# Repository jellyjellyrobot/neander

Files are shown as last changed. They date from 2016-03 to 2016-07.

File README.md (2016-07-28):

# Neander

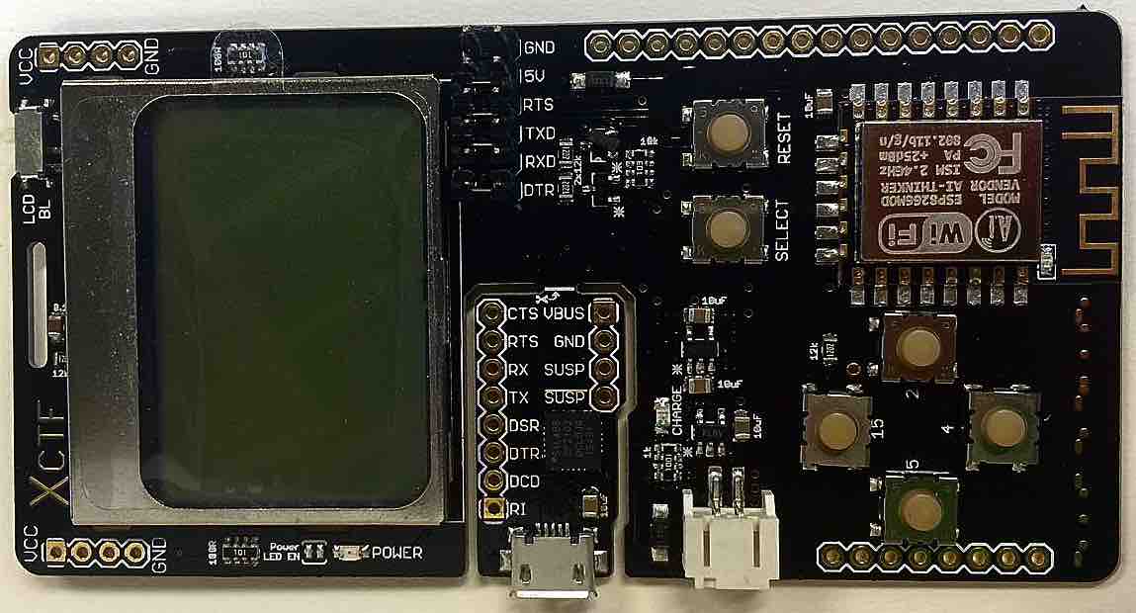
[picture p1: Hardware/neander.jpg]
Neander


The Neander is a microcontroller platform that is created for NUS Greyhats' X-CTF.

This board is based on the ESP8266 microcontroller series by Espressif and derives certain components from Adafruit's Feather and Sparkfun's Thing based on the same microcontroller platform.

## Specifications

- ESP8266 32 bit Microcontroller platform with Integrated 802.11 b/g/n
- Auto-Reset
- Deep Sleep option (enabled)
- 500mA 3.3V Voltage Regulator
- USB-Serial Interface (CP2102)
- 6 Buttons (including Reset)
- Lithium Polymer Charger
- Indicator LEDs (Charge, Power)
- Backlight LEDs and Switches

## Neander Accessory kit

The Neander comes with an accessory kit which includes the following

- Lithium Polymer Battery
- MicroUSB cable
- Short Lanyard (For CP2102)
- 10cm Dupont Jumper Cables (10 each: M-M, F-F, F-M)
- Single Row Headers 1*40 pin
- Double Row Headers 2*6 pin
- 6 Jumpers
- 2 Stickers

## Using the USB-Serial Adaptor

The on-board USB-Serial Adaptor is based on a Silabs CP2102 chip.

OS specific drivers can be found on the [manufacturer's website](http://www.silabs.com/products/mcu/Pages/USBtoUARTBridgeVCPDrivers.aspx). A tutorial on how to use this device can be found [here](https://learn.sparkfun.com/tutorials/cp2102-usb-to-serial-converter-hook-up-guide). The datasheet can be found [here](https://cdn.sparkfun.com/datasheets/BreakoutBoards/CP2102_v1.2.pdf).

## Interfacing with other electronics

The USB-Serial adaptor is supplied as a breakout board. If you need a serial adaptor "out in the field", you can choose to break it and solder on any 2.54mm compatible headers for convenience.

To interface the serial adaptor with other serial devices with the CP2102 in-situ, you may solder the double row headers found in the accessory packs and disconnect (desolder) all 5 SMD jumper pads.

## XCTF 2016

Here are the repositories for the [qualifiers] (https://github.com/NUSGreyhats/xctf-2016-quals-challenges) and [finals](https://github.com/NUSGreyhats/x-ctf-2016-finals).

## Contributors

Jacob  
Darell  
Yu Siang  
Jeremias

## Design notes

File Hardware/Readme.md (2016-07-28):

#Hardware

## Stages

This board was designed in 3 stages. 2 Prototypes were made (with mistakes :D) and the final board turned out pretty ok. Lucky us!

##Bill of Materials

The [Bill of Materials](https://docs.google.com/spreadsheets/d/1qAbk1U9EDFSMrGZ68tAHjeOSaGbgNGMX1J6-07fJV7c/edit?usp=sharing) can be found here!

## Production Writeups

Darell (@geekman) has produced a great writeup [here](http://irq5.io/2016/06/22/designing-the-x-ctf-2016-badge/)!

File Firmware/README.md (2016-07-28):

# Firmwares

## Firmware 1: XCTF

You can find the firmware provided during the competition [here](https://github.com/geekman/badger)! The writeup's [here](http://irq5.io/2016/07/19/x-ctf-2016-badge-firmware/)!

## Firmware 2: Test harness

This repository hosts the test harness for the ESP-8266 based Neander board.

## Arduino programming setup

The [Arduino IDE](https://www.arduino.cc/en/Main/Software) can be used to upload code to the Neander board.

To setup your Arduino IDE environment to compile and upload code to the Neander, you may refer to [this tutorial](https://learn.adafruit.com/adafruit-feather-huzzah-esp8266/using-arduino-ide).

## Serial programming/debugging setup

There are many serial programming utilities for the ESP8266 chips, we support [this](https://github.com/themadinventor/esptool). You can also use [this](https://github.com/igrr/esptool-ck). **YMMV**

``` sh
# installs esptool.py, a python utility that allows for serial programming and debugging of ESP8266 chips
pip install esptool
```

## Firmware Upload

The flash mode, size and frequency have to be set to the specific values based on the ESP12-F modules.

``` sh
esptool.py -p {insert port here} write_flash 0x00000 firmware/0x00000.bin 0x40000 firmware/0x40000.bin --flash_mode dio --flash_size 32m --flash_freq 40m
```

## Firmware Dump

This command dumps the flash memory from the region 0x0000 to 0x7490 to firmware/0x00000.bin.dump

``` sh
esptool.py -p {insert port here} read_flash 0x0000 0x7490 firmware/0x00000.bin.dump
```

## GCC Toolchain setup

We use [esp-open-sdk](https://github.com/pfalcon/esp-open-sdk), a collection of open-source utilities for compilation of source code to the xtensa instruction set architecture (used in ESP8266).

Once set up, you may reference the xtensa toolchain by 

```
export PATH={installation_dir}/esp-open-sdk/xtensa-lx106-elf/bin:$PATH
```

## Compilation and Upload of test suite

```sh
make rebuild
```

## Wiki

You can refer to [esp8266-wiki](https://github.com/esp8266/esp8266-wiki/wiki) learn more about the ESP8266, its features, architecture, boot process and memory map.

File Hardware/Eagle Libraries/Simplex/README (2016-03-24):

finest footprints for exotic devices. compatible with Eagle v6.0 or greater.

distributed under the GPLv3 license. provided as-is without any warranty. 

contains footprints for the following devices:

Simplex-Battery
    - Renata HU2032-LF Li 2032 battery holder

Simplex-Connectors
    - Lumberg KLBR4
    - Molex 0530470210
    - Molex 0530480210
    - Molex 0530470410
    - Molex 0530480410
    - Molex 0530470610
    - Molex 0530480610
    - Molex 78800001 mini SIM
    - Amphenol SIMLOCK "C707 10M006 000 2"
    - 2x4pin 3M IDC connector
    - 2x6pin 3M IDC connector
    - DG58C-B-02P-13 2 pole Degson Electronics screw terminal
    - DG58C-B-03P-13 3 pole Degson Electronics screw terminal
    - DG58C-B-04P-13 4 pole Degson Electronics screw terminal
    - DG58C-B-08P-13 8 pole Degson Electronics screw terminal

Simplex-DiscreteSemi
    - MOSFET-P channel - sot23-3, sot23-3 power, d-pak
    - MOSFET-N channel - sot23-3, sot23-3 power, d-pak
    - SMF05C

Simplex-FreqCtrl
    - 5x3.2mm crystal
    - 3.2x1.5mm crystal

Simplex-Fuses
    - 0805 resettable fuse
    - 1210 resettable fuse
    - Eastern Beaver Power Center 8

Simplex-ICs
    - DS3231
    - Vishay TSOP312x (vertical and horizontal)
    - Linear LTC2991
    - Texas Instruments TPS3613
    - Texas Instruments BQ24072
    - Texas Instruments ADS1110
    - Texas Instruments PGA2311
    - GlobalTop FGPMMOPA6H
    - sim900
    - STK461, STK463, STK465
    - linear regulators in a D2PAK package
    - Cypress FM24Vxx serial F-RAM
    - LM2674

Simplex-Jumpers
    - 4 way solder jumper

Simplex-rlc
    - 0805 inductor
    - yageo YC164 series resistor array
    - TO220 vertical and horizontal resistor

Simplex-Switches
    - 6x3.5mm tactile SPST-NO switch

author: Petre Rodan <petre.rodan@simplex.ro>
url:    https://github.com/rodan/Simplex-Eagle-Libraries

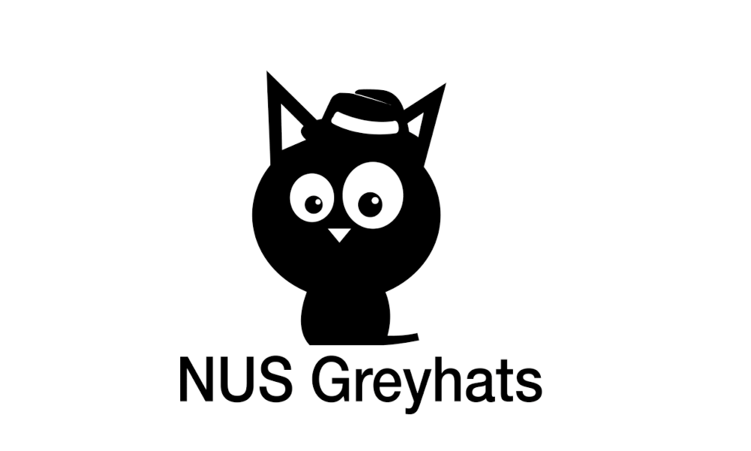
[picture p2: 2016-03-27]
Hardware/Eagle Libraries/GreyHats.bmp

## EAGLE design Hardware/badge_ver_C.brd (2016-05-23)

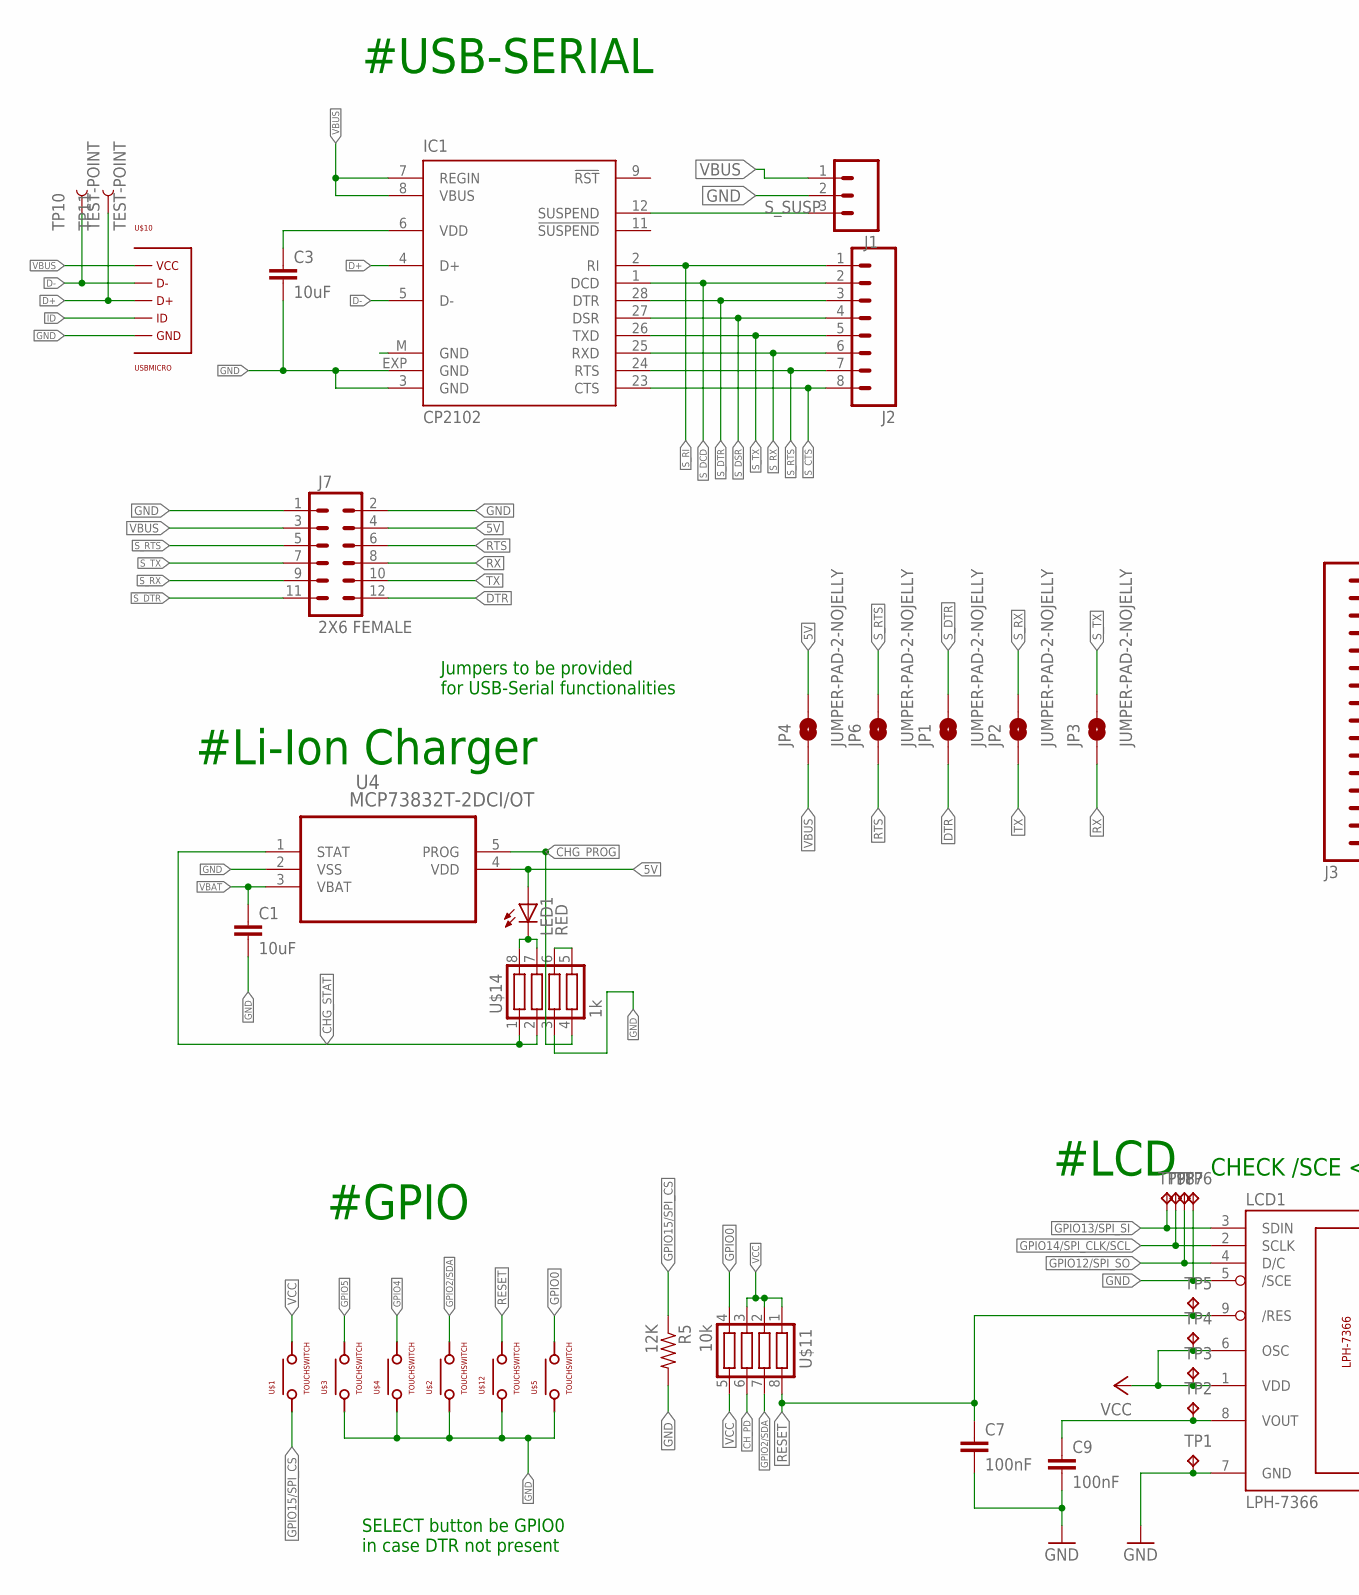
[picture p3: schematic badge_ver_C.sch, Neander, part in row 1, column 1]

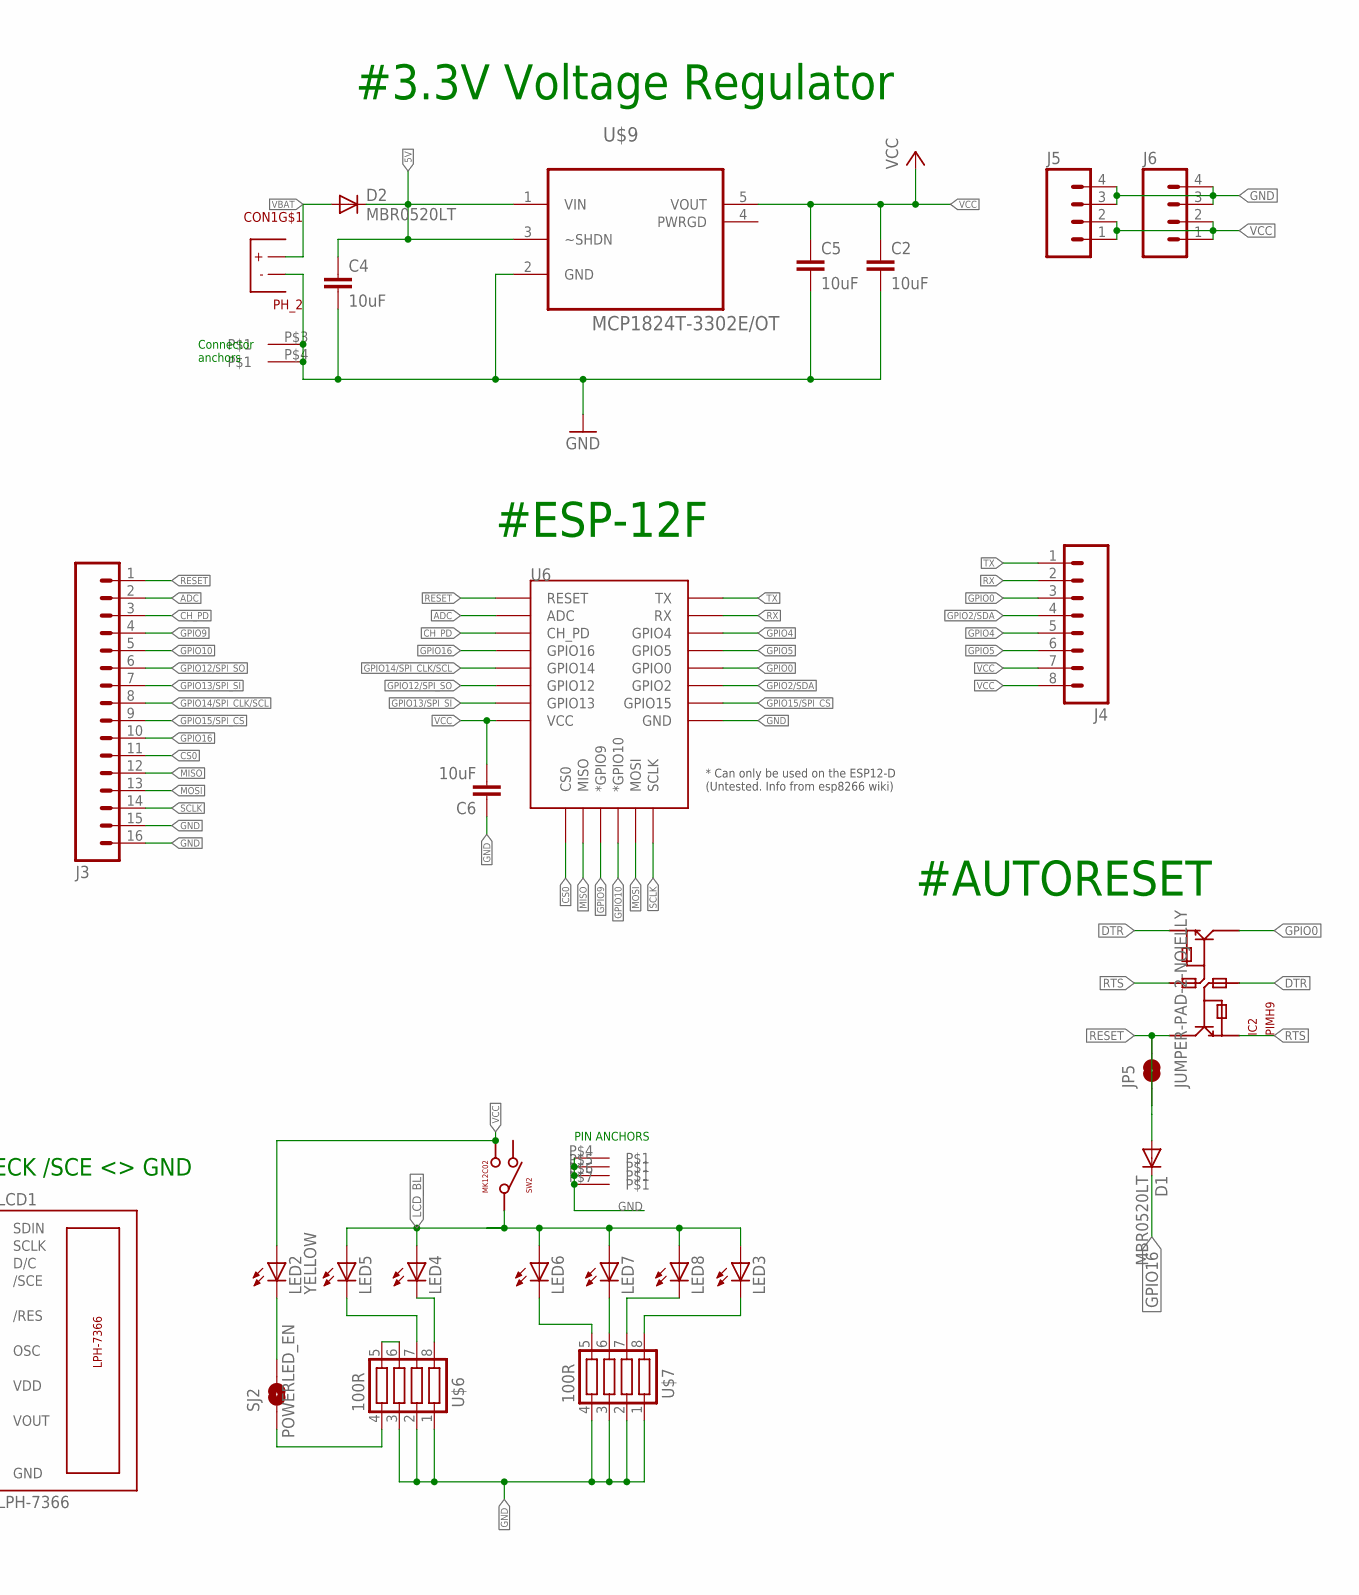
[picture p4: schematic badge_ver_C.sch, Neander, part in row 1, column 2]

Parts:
C1, C2, C3, C4, C5, C6: 10uF; 0805-CAP
C7, C9: 100nF; 0805-CAP
CON1: PH_2
D1, D2: MBR0520LT; SOD123
IC1: CP2102; MLP28
IC2: PIMH9; SOT457
J1: M03PTH; 1X03
J2: M08SILK_FEMALE_PTH; 1X08
J3: M16PTH; 1X16
J4: M08; 1X08_ROUND
J5, J6: M04PTH; 1X04
J7: 2X6 FEMALE; 2X6
JP1, JP2, JP3, JP4, JP5, JP6: JUMPER-PAD-2-NOJELLY; JELLYPAD-JUMPER-2-NO_NO_SILK
LCD1: LPH-7366
LED1: RED; SML0805
LED2: YELLOW; SML0805
LED3, LED4, LED5, LED6, LED7, LED8: LEDSML0805; SML0805
R5: 12K; 0805
SJ2: POWERLED_EN; SJ_2S-TRACE
SW2: MK12C02
TP1, TP2, TP3, TP4, TP5, TP6, TP7, TP8, TP9: TPB1,27; B1,27
TP10, TP11: TEST-POINT; PAD.02X.02_JELLY
U4: MCP73832T-2DCI/OT; SOT95P300X145-5N
U6: ESP12ESMD; ESP12E-SMD
U$1, U$2, U$3, U$4, U$5, U$12: TOUCHSWITCH; EVQQWN03W
U$6, U$7: 100R; YC164
U$9: MCP1824T-3302E/OT; SOT95P270X145-5N
U$10: USBMICRO
U$11: 10k; YC164
U$14: 1k; YC164

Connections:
5V: C4.1, D2.C, J7.4, JP4.2, LED1.A, U4.4 (VDD), U$9.1 (VIN), U$9.3 (~SHDN)
ADC: J3.2, U6.ADC
CHG_PROG: U4.5 (PROG), U$14.4
CHG_STAT: U4.1 (STAT), U$14.1, U$14.2
CH_PD: J3.3, U6.CH_PD, U$11.6
CS0: J3.11, U6.CS0
D+: IC1.4 (D+), TP11.P$1, U$10.P$D+
D-: IC1.5 (D-), TP10.P$1, U$10.P$D-
DTR: IC2.P$2, IC2.P$4, J7.12, JP1.1
GND: C1.2, C2.2, C3.2, C4.2, C5.2, C6.1, C7.2, C9.2, CON1.P$1, CON1.P$3, CON1.P$4, IC1.3 (GND), IC1.EXP (GND), J1.2, J3.15, J3.16, J5.3, J5.4, J6.3, J6.4, J7.1, J7.2, LCD1.5 (/SCE), LCD1.7 (GND), R5.2, SW2.P$4, SW2.P$5, SW2.P$6, SW2.P$7, TP1.TP, TP6.TP, U4.2 (VSS), U6.GND, U$2.P$1, U$2.P$4, U$3.P$1, U$3.P$4, U$4.P$1, U$4.P$4, U$5.P$1, U$5.P$4, U$6.1, U$6.2, U$6.3, U$7.1, U$7.2, U$7.3, U$7.4, U$9.2 (GND), U$10.P$GND, U$12.P$1, U$12.P$4, U$14.3
GPIO0: IC2.P$3, J4.3, U6.GPIO0, U$5.P$2, U$5.P$3, U$11.4
GPIO2/SDA: J4.4, U6.GPIO2, U$2.P$2, U$2.P$3, U$11.7
GPIO4: J4.5, U6.GPIO4, U$4.P$2, U$4.P$3
GPIO5: J4.6, U6.GPIO5, U$3.P$2, U$3.P$3
GPIO9: J3.4, U6.GPIO9 (*GPIO9)
GPIO10: J3.5, U6.GPIO10 (*GPIO10)
GPIO12/SPI_SO: J3.6, LCD1.4 (D/C), TP7.TP, U6.GPIO12
GPIO13/SPI_SI: J3.7, LCD1.3 (SDIN), TP9.TP, U6.GPIO13
GPIO14/SPI_CLK/SCL: J3.8, LCD1.2 (SCLK), TP8.TP, U6.GPIO14
GPIO15/SPI_CS: J3.9, R5.1, U6.GPIO15, U$1.P$1, U$1.P$4
GPIO16: D1.C, J3.10, U6.GPIO16
ID: U$10.P$ID
LCD_BL: LED3.A, LED4.A, LED5.A, LED6.A, LED7.A, LED8.A, SW2.P$2
MISO: J3.12, U6.MISO
MOSI: J3.13, U6.MOSI
unnamed: LED1.C, U$14.7, U$14.8
unnamed: U$14.5, U$14.6
unnamed: LED7.C, U$7.6
unnamed: LED8.C, U$7.7
unnamed: C9.1, LCD1.8 (VOUT), TP2.TP
unnamed: U$6.5, U$6.6
unnamed: LED4.C, U$6.8
unnamed: LED5.C, U$6.7
unnamed: LED3.C, U$7.8
unnamed: SJ2.1, U$6.4
unnamed: LED2.C, SJ2.2
unnamed: C3.1, IC1.6 (VDD)
unnamed: LED6.C, U$7.5
RESET: C7.1, D1.A, IC2.P$6, J3.1, JP5.1, JP5.2, LCD1.9 (/RES), TP5.TP, U6.RESET, U$11.8, U$12.P$2, U$12.P$3
RTS: IC2.P$1, IC2.P$5, J7.6, JP6.1
RX: J4.2, J7.8, JP3.1, U6.RXD0 (RX)
SCLK: J3.14, U6.SCLK
S_CTS: IC1.23 (CTS), J2.8
S_DCD: IC1.1 (DCD), J2.2
S_DSR: IC1.27 (DSR), J2.4
S_DTR: IC1.28 (DTR), J2.3, J7.11, JP1.2
S_RI: IC1.2 (RI), J2.1
S_RTS: IC1.24 (RTS), J2.7, J7.5, JP6.2
S_RX: IC1.25 (RXD), J2.6, J7.9, JP2.2
S_SUSP: IC1.12 (SUSPEND), J1.3
S_TX: IC1.26 (TXD), J2.5, J7.7, JP3.2
TX: J4.1, J7.10, JP2.1, U6.TXD0 (TX)
VBAT: C1.1, CON1.P$2, D2.A, U4.3 (VBAT)
VBUS: IC1.7 (REGIN), IC1.8 (VBUS), J1.1, J7.3, JP4.1, U$10.P$VCC
VCC: C2.1, C5.1, C6.2, J4.7, J4.8, J5.1, J5.2, J6.1, J6.2, LCD1.1 (VDD), LCD1.6 (OSC), LED2.A, SW2.P$3, TP3.TP, TP4.TP, U6.VCC, U$1.P$2, U$1.P$3, U$9.5 (VOUT), U$11.1, U$11.2, U$11.3, U$11.5

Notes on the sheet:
SELECT button be GPIO0 in case DTR not present
#LCD
#Li-Ion Charger
#3.3V Voltage Regulator
#USB-SERIAL
#GPIO
#AUTORESET
#ESP-12F
Jumpers to be provided for USB-Serial functionalities
CHECK /SCE <> GND
Connector anchors
PIN ANCHORS

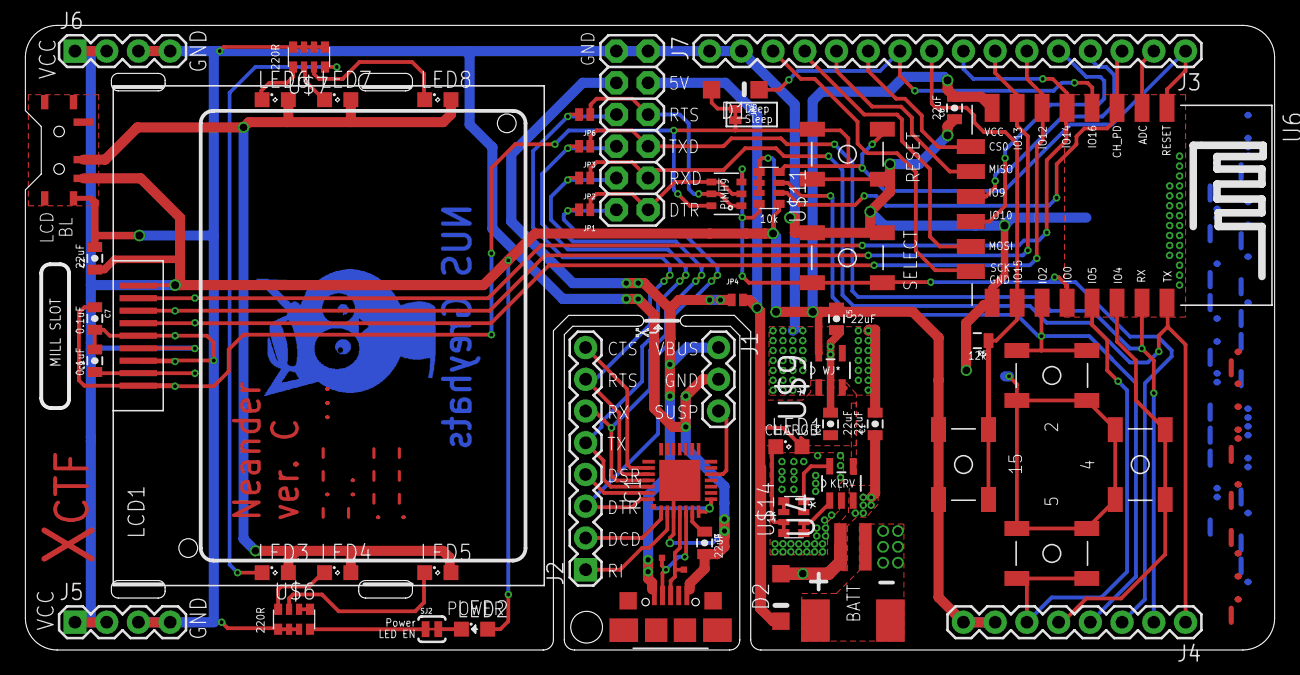
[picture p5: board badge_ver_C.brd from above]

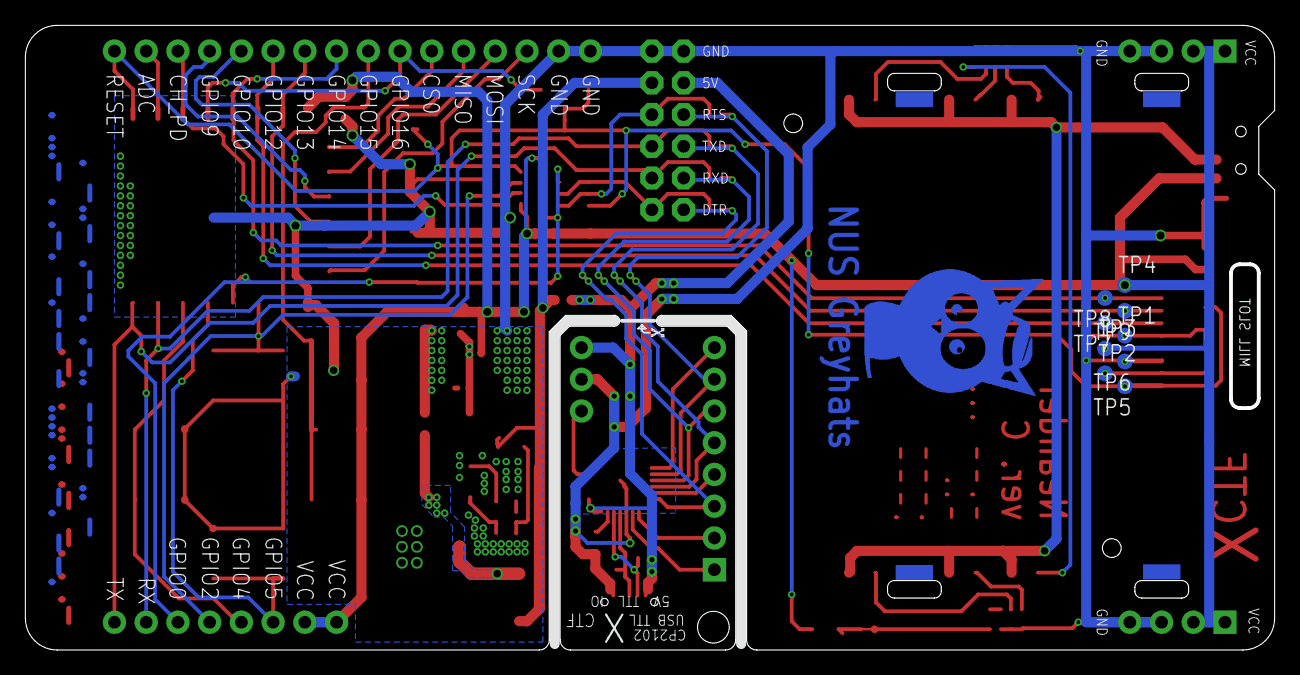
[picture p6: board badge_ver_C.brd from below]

Board: 2 copper layers, 100.0 x 50.0 mm, 63 parts (9 on the bottom side), 54 nets.

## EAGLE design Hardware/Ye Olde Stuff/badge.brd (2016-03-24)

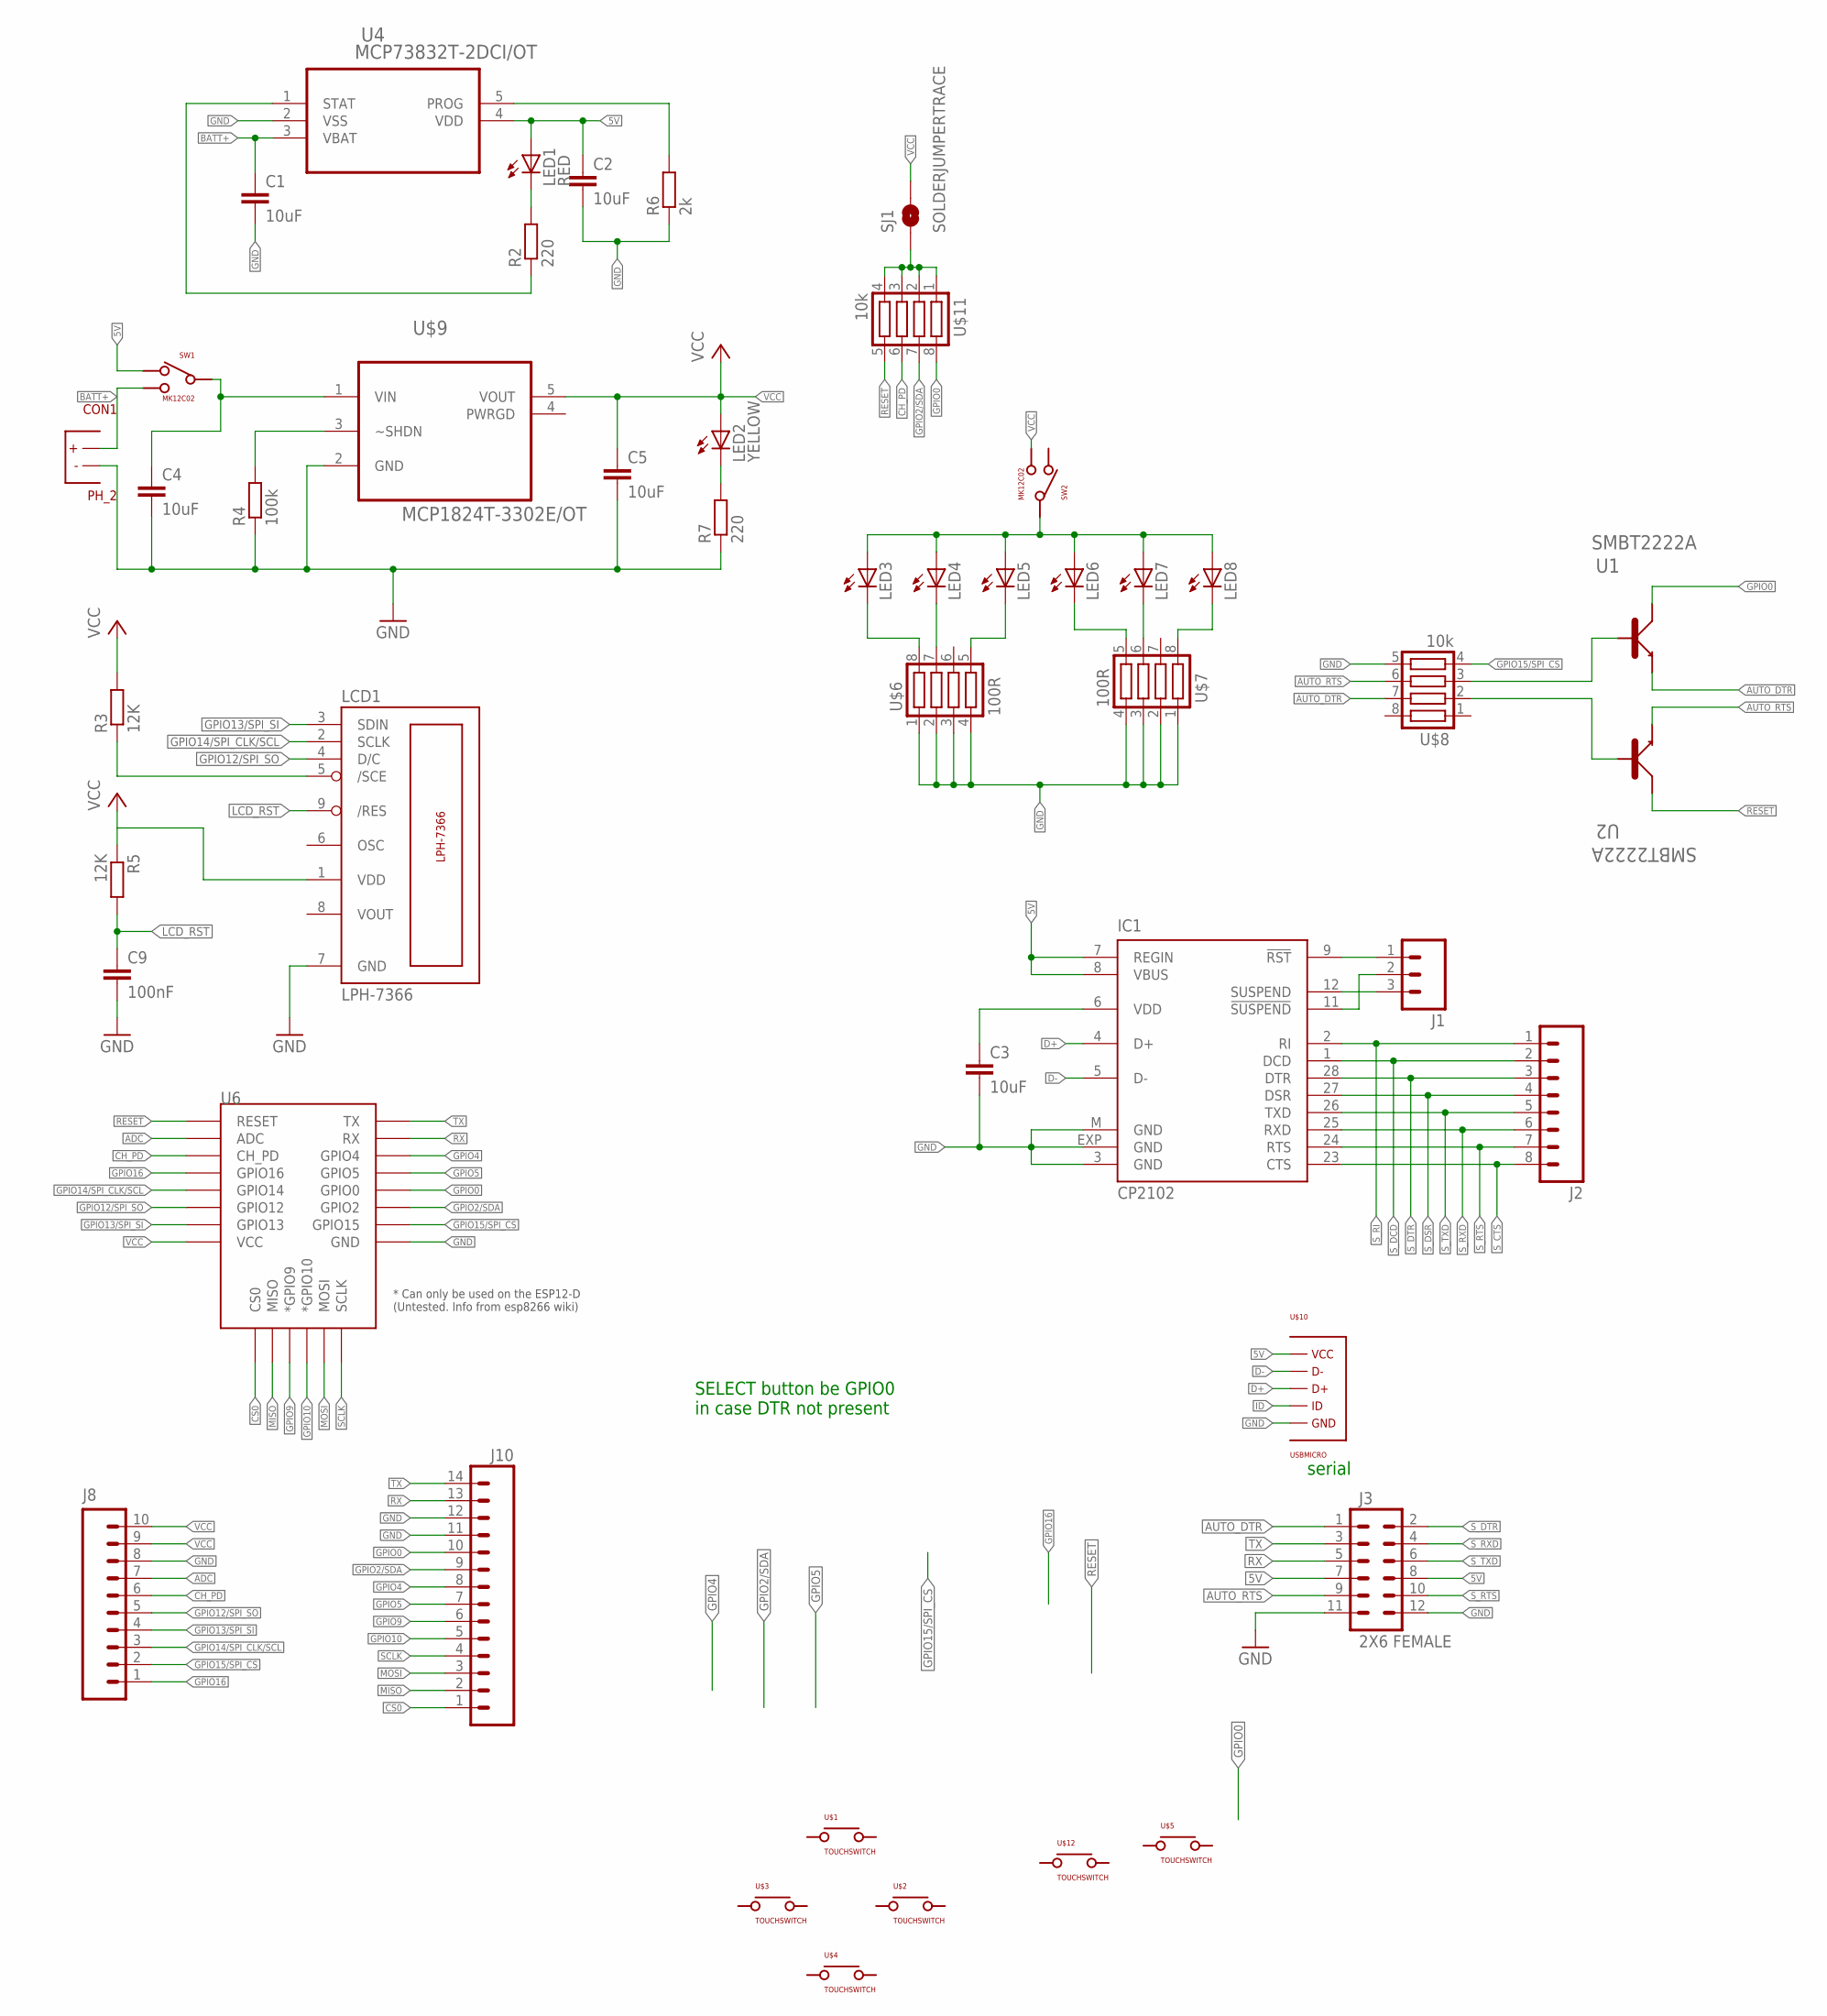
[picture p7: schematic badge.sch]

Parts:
C1, C2, C3, C4, C5: 10uF; C0603K
C9: 100nF; C0603K
CON1: PH_2
IC1: CP2102; MLP28
J1: M03PTH; 1X03
J2: M08SILK_FEMALE_PTH; 1X08
J3: 2X6 FEMALE; 2X6
J8: M10SILK_FEMALE_PTH; 1X10
J10: M14; 1X14
LCD1: LPH-7366
LED1: RED; SML0805
LED2: YELLOW; SML0805
LED3, LED4, LED5, LED6, LED7, LED8: LEDSML0805; SML0805
R2, R7: 220; R0603W
R3, R5: 12K; R0603W
R4: 100k; R0603W
R6: 2k; R0603W
SJ1: SOLDERJUMPERTRACE; SJ_2S-TRACE
SW1, SW2: MK12C02
U1, U2: SMBT2222A; SOT95P290X110-3N
U4: MCP73832T-2DCI/OT; SOT95P300X145-5N
U6: ESP12ESMD; ESP12E-SMD
U$1, U$2, U$3, U$4, U$5, U$12: TOUCHSWITCH; EVQQWN03W
U$6, U$7: 100R; YC164
U$8, U$11: 10k; YC164
U$9: MCP1824T-3302E/OT; SOT95P270X145-5N
U$10: USBMICRO

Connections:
5V: C2.1, IC1.7 (REGIN), IC1.8 (VBUS), J3.7, J3.8, LED1.A, SW1.P$2, U4.4 (VDD), U$10.P$VCC
ADC: J8.7, U6.ADC
AUTO_DTR: J3.1, U1.2 (E), U$8.7
AUTO_RTS: J3.9, U2.2 (E), U$8.6
BATT+: C1.1, CON1.P$2, SW1.P$3, U4.3 (VBAT)
CH_PD: J8.6, U6.CH_PD, U$11.6
CS0: J10.1, U6.CS0
D+: IC1.4 (D+), U$10.P$D+
D-: IC1.5 (D-), U$10.P$D-
GND: C1.2, C2.2, C3.2, C4.2, C5.2, C9.2, CON1.P$1, IC1.3 (GND), IC1.EXP (GND), IC1.M (GND), J3.11, J3.12, J8.8, J10.11, J10.12, LCD1.7 (GND), R4.1, R6.1, R7.1, U4.2 (VSS), U6.GND, U$6.1, U$6.2, U$6.3, U$6.4, U$7.1, U$7.2, U$7.3, U$7.4, U$8.5, U$9.2 (GND), U$10.P$GND
GPIO0: J10.10, U1.3 (C), U6.GPIO0, U$11.8
GPIO2/SDA: J10.9, U6.GPIO2, U$11.7
GPIO4: J10.8, U6.GPIO4
GPIO5: J10.7, U6.GPIO5
GPIO9: J10.6, U6.GPIO9 (*GPIO9)
GPIO10: J10.5, U6.GPIO10 (*GPIO10)
GPIO12/SPI_SO: J8.5, LCD1.4 (D/C), U6.GPIO12
GPIO13/SPI_SI: J8.4, LCD1.3 (SDIN), U6.GPIO13
GPIO14/SPI_CLK/SCL: J8.3, LCD1.2 (SCLK), U6.GPIO14
GPIO15/SPI_CS: J8.2, U6.GPIO15, U$8.4
GPIO16: J8.1, U6.GPIO16
ID: U$10.P$ID
LCD_RST: C9.1, LCD1.9 (/RES), R5.2
MISO: J10.2, U6.MISO
MOSI: J10.3, U6.MOSI
unnamed: C4.1, SW1.P$1, U$9.1 (VIN)
unnamed: LED3.A, LED4.A, LED5.A, LED6.A, LED7.A, LED8.A, SW2.P$1
unnamed: LCD1.5 (/SCE), R3.1
unnamed: R4.2, U$9.3 (~SHDN)
unnamed: SJ1.1, U$11.1, U$11.2, U$11.3, U$11.4
unnamed: R6.2, U4.5 (PROG)
unnamed: LED2.C, R7.2
unnamed: LED7.C, U$7.6
unnamed: LED1.C, R2.2
unnamed: R2.1, U4.1 (STAT)
unnamed: LED3.C, U$6.8
unnamed: LED4.C, U$6.7
unnamed: LED5.C, U$6.5
unnamed: U1.1 (B), U$8.3
unnamed: IC1.11 (!SUSPEND), J1.2
unnamed: IC1.12 (SUSPEND), J1.3
unnamed: U2.1 (B), U$8.2
unnamed: IC1.9 (!RST), J1.1
unnamed: C3.1, IC1.6 (VDD)
unnamed: LED6.C, U$7.5
unnamed: LED8.C, U$7.8
RESET: U2.3 (C), U6.RESET, U$11.5
RX: J3.5, J10.13, U6.RXD0 (RX)
SCLK: J10.4, U6.SCLK
S_CTS: IC1.23 (CTS), J2.8
S_DCD: IC1.1 (DCD), J2.2
S_DSR: IC1.27 (DSR), J2.4
S_DTR: IC1.28 (DTR), J2.3, J3.2
S_RI: IC1.2 (RI), J2.1
S_RTS: IC1.24 (RTS), J2.7, J3.10
S_RXD: IC1.25 (RXD), J2.6, J3.4
S_TXD: IC1.26 (TXD), J2.5, J3.6
TX: J3.3, J10.14, U6.TXD0 (TX)
VCC: C5.1, J8.9, J8.10, LCD1.1 (VDD), LED2.A, R3.2, R5.1, SJ1.2, SW2.P$3, U6.VCC, U$9.5 (VOUT)

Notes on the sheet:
serial
SELECT button be GPIO0 in case DTR not present

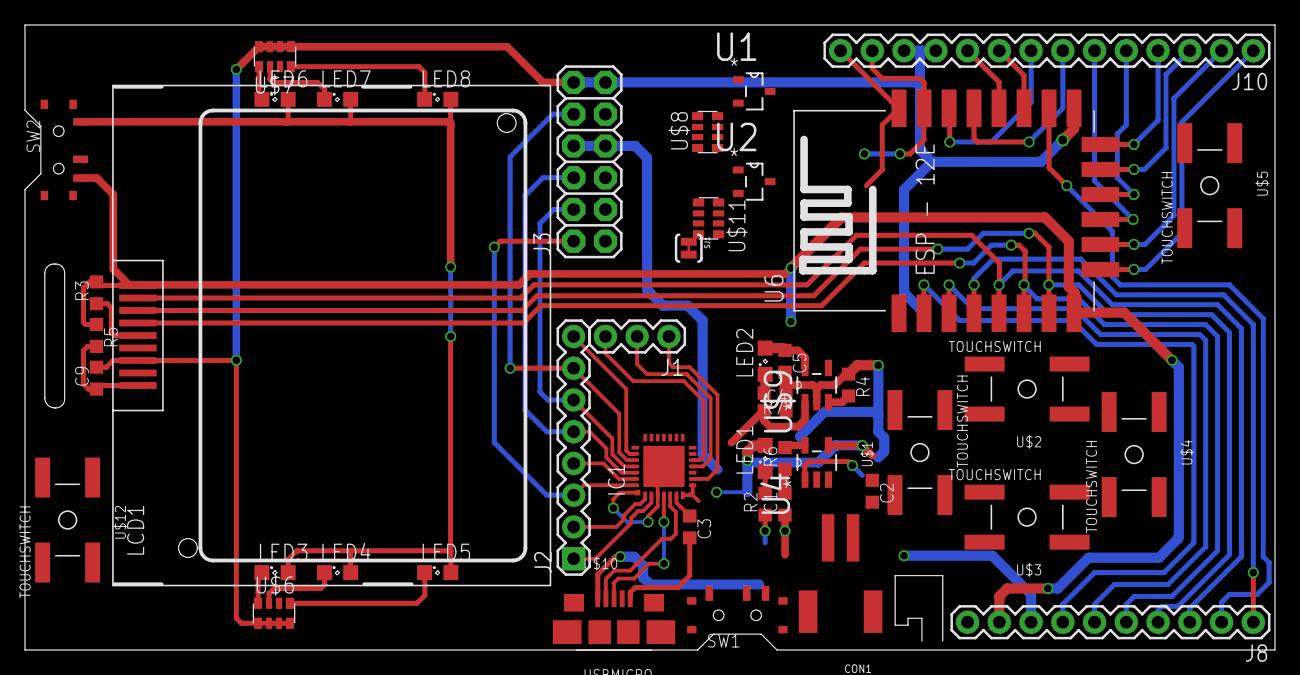
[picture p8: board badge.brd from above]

Board: 2 copper layers, 100.0 x 50.0 mm, 47 parts (0 on the bottom side), 58 nets.

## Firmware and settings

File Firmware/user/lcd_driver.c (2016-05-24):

#include "ets_sys.h"
#include "osapi.h"
#include "c_types.h"
#include "gpio.h"
#include "os_type.h"
#include "user_config.h"
#include "user_interface.h"
#include "stdout/stdout.h"
#include "pcd8544/pcd8544.h"
#include "easygpio/easygpio.h"

//http://www.introtoarduino.com/utils/pcd8544.html

static uint8_t test_logo[] = {
  0x15, 0x00, 0x01, 0x6C, 0x11, 0x6C, 0x00, 0x7C, 0x44, 0x44, 0x00, 0x04, 0x7C, 0x04, 0x00, 0x7C, 0x14, 0x14, 0x00, 0x00, 0x00, 0x00, 0x00, 0x7C, 0x08, 0x10, 0x7C, 0x00, 0x7C, 0x54, 0x54, 0x00, 0x78, 0x14, 0x78, 0x00, 0x7C, 0x08, 0x10, 0x7C, 0x00, 0x7C, 0x44, 0x38, 0x00, 0x7C, 0x54, 0x54, 0x00, 0x7C, 0x14, 0x68, 0x00, 0x00, 0x00, 0x00, 0x00, 0x3C, 0x40, 0x3C, 0x00, 0x00, 0x7C, 0x00, 0x40, 0x00, 0x78, 0x14, 0x78, 0x00, 0x00, 0x00, 0x00, 0x00, 0x00, 0x00, 0x00, 0x00, 0x00, 0x01, 0x00, 0x01, 0x00, 0x15,
  0x00, 0x00, 0x00, 0x01, 0x1F, 0x01, 0x00, 0x1F, 0x15, 0x15, 0x00, 0x17, 0x15, 0x1D, 0x00, 0x01, 0x1F, 0x01, 0x00, 0x00, 0x00, 0x00, 0x00, 0x17, 0x15, 0x1D, 0x00, 0x1F, 0x10, 0x1F, 0x00, 0x11, 0x1F, 0x11, 0x00, 0x01, 0x1F, 0x01, 0x00, 0x1F, 0x15, 0x15, 0x00, 0x00, 0x00, 0x00, 0x00, 0x00, 0x00, 0x00, 0x00, 0x00, 0x00, 0x00, 0x00, 0x00, 0x00, 0x00, 0x00, 0x00, 0x00, 0x00, 0x00, 0x00, 0x00, 0x00, 0x00, 0x00, 0x00, 0x00, 0x00, 0x00, 0x00, 0x00, 0x00, 0x00, 0x00, 0x00, 0x00, 0x00, 0x00, 0x00, 0x00, 0x00,
  0x00, 0x00, 0x00, 0x00, 0x00, 0x00, 0x00, 0x00, 0x00, 0x00, 0x00, 0x00, 0x00, 0x00, 0x00, 0x00, 0x00, 0x00, 0x00, 0x00, 0x00, 0x00, 0x00, 0x00, 0x00, 0x00, 0x00, 0x00, 0x00, 0x00, 0x00, 0x00, 0x00, 0x00, 0x00, 0x00, 0x00, 0x00, 0x00, 0x00, 0x00, 0x00, 0x00, 0x00, 0x00, 0x00, 0x00, 0x00, 0x00, 0x00, 0x00, 0x00, 0x00, 0x00, 0x00, 0x00, 0x00, 0x00, 0x00, 0x00, 0x00, 0x00, 0x00, 0x00, 0x00, 0x00, 0x00, 0x00, 0x00, 0x00, 0x00, 0x00, 0x00, 0x00, 0x00, 0x00, 0x00, 0x00, 0x00, 0x00, 0x00, 0x00, 0x00, 0x00,
  0x00, 0x00, 0x00, 0x00, 0x00, 0x00, 0x00, 0x00, 0x00, 0x00, 0x00, 0x00, 0x00, 0x00, 0x00, 0x00, 0x00, 0x00, 0x00, 0x00, 0x00, 0x00, 0x00, 0x00, 0x00, 0x00, 0x00, 0x00, 0x00, 0x00, 0x00, 0x00, 0x00, 0x00, 0x00, 0x00, 0x00, 0x00, 0x00, 0x00, 0x00, 0x00, 0x00, 0x00, 0x00, 0x00, 0x00, 0x00, 0x00, 0x00, 0x00, 0x00, 0x00, 0x00, 0x00, 0x00, 0x00, 0x00, 0x00, 0x00, 0x00, 0x00, 0x00, 0x00, 0x00, 0x00, 0x00, 0x00, 0x00, 0x00, 0x00, 0x00, 0x00, 0x00, 0x00, 0x00, 0x00, 0x00, 0x00, 0x00, 0x00, 0x00, 0x00, 0x00,
  0x00, 0x00, 0x00, 0x00, 0x00, 0x00, 0x00, 0x00, 0x00, 0x00, 0x00, 0x00, 0x00, 0x00, 0x00, 0x00, 0x00, 0x00, 0x00, 0x00, 0x00, 0x00, 0x00, 0x00, 0x00, 0x00, 0x00, 0x00, 0x00, 0x00, 0x00, 0x00, 0x00, 0x00, 0x00, 0x00, 0x00, 0x00, 0x00, 0x00, 0x00, 0x00, 0x00, 0x00, 0x00, 0x00, 0x00, 0x00, 0x00, 0x00, 0x00, 0x00, 0x00, 0x00, 0x00, 0x00, 0x00, 0x00, 0x00, 0x00, 0x00, 0x00, 0x00, 0x00, 0x00, 0x00, 0x00, 0x00, 0x00, 0x00, 0x00, 0x00, 0x00, 0x00, 0x00, 0x00, 0x00, 0x00, 0x00, 0x00, 0x00, 0x00, 0x00, 0x00,
  0xA8, 0x00, 0x80, 0x00, 0x80, 0x00, 0x00, 0x00, 0x00, 0x00, 0x00, 0x00, 0x00, 0x00, 0x00, 0x00, 0x00, 0x00, 0x00, 0x00, 0x00, 0x00, 0x00, 0x00, 0x00, 0x00, 0x00, 0x00, 0x00, 0x00, 0x00, 0x00, 0x00, 0x00, 0x00, 0x00, 0x00, 0x00, 0x00, 0x00, 0x00, 0x00, 0x00, 0x00, 0x00, 0x00, 0x00, 0x00, 0x00, 0x00, 0x00, 0x00, 0x00, 0x00, 0x00, 0x00, 0x00, 0x00, 0x00, 0x00, 0x00, 0x00, 0x00, 0x00, 0x00, 0x00, 0x00, 0x00, 0x00, 0x00, 0x00, 0x00, 0x00, 0x00, 0x00, 0x00, 0x00, 0x00, 0x00, 0x80, 0x00, 0x80, 0x00, 0xA8
};

#define user_procLcdUpdatePeriod 350
#define user_procTaskPrio 0
#define user_procTaskQueueLen 1

static volatile os_timer_t loop_timer;
os_event_t user_procTaskQueue[user_procTaskQueueLen];
static PCD8544_Settings pcd8544_settings;
static int contrast = 50;

void user_init(void);
static void loop(os_event_t *events);
static void nop_procTask(os_event_t *events);
static bool blah[10];


//Main code function
static void ICACHE_FLASH_ATTR
loop(os_event_t *events) {
  static uint32_t loopIterations = 0;
  loopIterations+=1;
  PCD8544_setContrast(contrast);
  if (loopIterations < 10) {
    PCD8544_lcdImage(test_logo);
  } else if (loopIterations == 10){
    PCD8544_lcdClear();
  } else {

    // Draw a Box
    PCD8544_drawLine();
    int a=0;
    PCD8544_gotoXY(10,1);
    // Put text in Box
    if (blah[0] && blah[1] && blah[2] && blah[3] && blah[4] && blah[5] && blah[6] && blah[7] && blah[8] && blah[9]){
      PCD8544_lcdPrint("TEST COMP");
    }else{
      PCD8544_lcdPrint("XCTF TEST");
    }
    
    PCD8544_gotoXY(24,2);

    if (gpio_input_get() & 1) {
      PCD8544_lcdCharacter('H');
      blah[5] = true;
    }else{
      PCD8544_lcdCharacter('h');
      blah[0] = true;
    }

    if (gpio_input_get() >> 2 & 1) {
      PCD8544_lcdCharacter('E');
      blah[5+1] = true;
    }else{
      PCD8544_lcdCharacter('e');
      blah[1] = true;
    }

    if (gpio_input_get() >> 4 & 1) {
      PCD8544_lcdCharacter('L');
      blah[5+2] = true;
    }else{
      PCD8544_lcdCharacter('l');
      blah[2] = true;
    }

    if (gpio_input_get() >> 5 & 1) {
      PCD8544_lcdCharacter('L');
      blah[5+3] = true;
    }else{
      PCD8544_lcdCharacter('l');
      if (contrast != 0){
        contrast--;
      }
      blah[3] = true;
    }

    if (!(gpio_input_get() >> 15 & 1)) {
      PCD8544_lcdCharacter('O');
      blah[5+4] = true;
    }else{
      PCD8544_lcdCharacter('o');
      if (contrast != 100){
        contrast++;
      }
      blah[4] = true;
    }

    if (loopIterations & 1){
      PCD8544_lcdCharacter(' ');
      PCD8544_lcdCharacter('=');
      // Draw + at this position
      PCD8544_gotoXY(10,2);
      PCD8544_lcdCharacter('=');
    } else {
      //PCD8544_gotoXY(24,2);
      PCD8544_lcdCharacter(' ');
      PCD8544_lcdCharacter('-');
      // Draw - at this position
      PCD8544_gotoXY(10,2);
      PCD8544_lcdCharacter('-');
    }
    //uint8_t contrast = ((loopIterations << 2)+25) & 0x3f; // +25 so that we start in the visible range
    PCD8544_setContrast(contrast);
    PCD8544_gotoXY(2,3);
    PCD8544_lcdPrint(" contrast:");
    char buf[] = "         ";
    os_sprintf(buf,"%d   ", contrast);
    PCD8544_gotoXY(32,4);
    PCD8544_lcdPrint(buf);
    os_printf("Updating display. Contrast = %d\n", contrast);
  }
}

/**
 * Setup program. When user_init runs the debug printouts will not always
 * show on the serial console. So i run the inits in here, 2 seconds later.
 */
static void ICACHE_FLASH_ATTR
setup(void) {
  pcd8544_settings.lcdVop = 0xB1; // -> influences the contrast by differing voltage levels
  pcd8544_settings.tempCoeff = 0x04; //04
  pcd8544_settings.biasMode = 0x13; //10 -> influences the flickering and contrast settings thru voltage trigger levels
  pcd8544_settings.inverse = false;

  pcd8544_settings.resetPin = -1; // 4;
  pcd8544_settings.scePin = -1; //5;

  pcd8544_settings.dcPin = 12;
  pcd8544_settings.sdinPin = 13;
  pcd8544_settings.sclkPin = 14;

  PCD8544_init(&pcd8544_settings);
  os_printf("pcd8544 lcd initiated\n");

  int select_ = 0;
  int up_ = 15;
  int down_ = 4;
  int left_ = 5;
  int right_ = 2;

  easygpio_pinMode(select_, EASYGPIO_NOPULL, EASYGPIO_INPUT);
  easygpio_pinMode(up_, EASYGPIO_NOPULL, EASYGPIO_INPUT);
  easygpio_pinMode(down_, EASYGPIO_PULLUP, EASYGPIO_INPUT);
  easygpio_pinMode(left_, EASYGPIO_PULLUP, EASYGPIO_INPUT);
  easygpio_pinMode(right_, EASYGPIO_NOPULL, EASYGPIO_INPUT);

  // Start loop timer
  os_timer_disarm(&loop_timer);
  os_timer_setfn(&loop_timer, (os_timer_func_t *) loop, NULL);
  os_timer_arm(&loop_timer, user_procLcdUpdatePeriod, true);
}

//Do nothing function
static void ICACHE_FLASH_ATTR
nop_procTask(os_event_t *events) {
  os_delay_us(10);
}

//Init function 
void ICACHE_FLASH_ATTR
user_init(void)
{
  // Make uart0 work with just the TX pin. Baud:115200,n,8,1
  // The RX pin is now free for GPIO use.
  stdout_init();

  // turn off WiFi for this console only demo
  wifi_station_set_auto_connect(false);
  wifi_station_disconnect();

  os_timer_disarm(&loop_timer);

  // Start setup timer
  os_timer_setfn(&loop_timer, (os_timer_func_t *) setup, NULL);
  os_timer_arm(&loop_timer, user_procLcdUpdatePeriod*2, false);

  //Start no-operation os task
  system_os_task(nop_procTask, user_procTaskPrio, user_procTaskQueue, user_procTaskQueueLen);
  system_os_post(user_procTaskPrio, 0, 0);
}

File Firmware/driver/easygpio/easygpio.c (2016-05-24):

/*
* easygpio.c
*
* Copyright (c) 2015, eadf (https://github.com/eadf)
* All rights reserved.
*
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
* THIS SOFTWARE IS PROVIDED BY THE COPYRIGHT HOLDERS AND CONTRIBUTORS "AS IS"
* AND ANY EXPRESS OR IMPLIED WARRANTIES, INCLUDING, BUT NOT LIMITED TO, THE
* IMPLIED WARRANTIES OF MERCHANTABILITY AND FITNESS FOR A PARTICULAR PURPOSE
* ARE DISCLAIMED. IN NO EVENT SHALL THE COPYRIGHT OWNER OR CONTRIBUTORS BE
* LIABLE FOR ANY DIRECT, INDIRECT, INCIDENTAL, SPECIAL, EXEMPLARY, OR
* CONSEQUENTIAL DAMAGES (INCLUDING, BUT NOT LIMITED TO, PROCUREMENT OF
* SUBSTITUTE GOODS OR SERVICES; LOSS OF USE, DATA, OR PROFITS; OR BUSINESS
* INTERRUPTION) HOWEVER CAUSED AND ON ANY THEORY OF LIABILITY, WHETHER IN
* CONTRACT, STRICT LIABILITY, OR TORT (INCLUDING NEGLIGENCE OR OTHERWISE)
* ARISING IN ANY WAY OUT OF THE USE OF THIS SOFTWARE, EVEN IF ADVISED OF THE
* POSSIBILITY OF SUCH DAMAGE.
*/

#include "easygpio/easygpio.h"
#include "gpio.h"
#include "osapi.h"
#include "ets_sys.h"

/**
 * Returns the number of active pins in the gpioMask.
 */
uint8_t ICACHE_FLASH_ATTR
easygpio_countBits(uint32_t gpioMask) {

  uint8_t i=0;
  uint8_t numberOfPins=0;
  for (i=0; i<32; i++){
    numberOfPins += (gpioMask & 1<<i)?1:0;
  }
  return numberOfPins;
}

/**
 * Returns the gpio name and func for a specific pin.
 */
bool ICACHE_FLASH_ATTR
easygpio_getGPIONameFunc(uint8_t gpio_pin, uint32_t *gpio_name, uint8_t *gpio_func ) {

  if (gpio_pin == 6 || gpio_pin == 7 || gpio_pin == 8 || gpio_pin == 11 || gpio_pin >= 17) {
    os_printf("easygpio_getGPIONameFunc Error: There is no GPIO%d, check your code\n", gpio_pin);
    return false;
  }
  if (gpio_pin == 16) {
    os_printf("easygpio_getGPIONameFunc Error: GPIO16 is not implemented\n");
    return false;
  }
  switch ( gpio_pin ) {
    case 0:
      *gpio_func = FUNC_GPIO0;
      *gpio_name = PERIPHS_IO_MUX_GPIO0_U;
      return true;
    case 1:
      *gpio_func = FUNC_GPIO1;
      *gpio_name = PERIPHS_IO_MUX_U0TXD_U;
      return true;
    case 2:
      *gpio_func = FUNC_GPIO2;
      *gpio_name = PERIPHS_IO_MUX_GPIO2_U;
      return true;
    case 3:
      *gpio_func = FUNC_GPIO3;
      *gpio_name = PERIPHS_IO_MUX_U0RXD_U;
      return true;
    case 4:
      *gpio_func = FUNC_GPIO4;
      *gpio_name = PERIPHS_IO_MUX_GPIO4_U;
      return true;
    case 5:
      *gpio_func = FUNC_GPIO5;
      *gpio_name = PERIPHS_IO_MUX_GPIO5_U;
      return true;
    case 9:
      *gpio_func = FUNC_GPIO9;
      *gpio_name = PERIPHS_IO_MUX_SD_DATA2_U;
      return true;
    case 10:
      *gpio_func = FUNC_GPIO10;
      *gpio_name = PERIPHS_IO_MUX_SD_DATA3_U;
      return true;
    case 12:
      *gpio_func = FUNC_GPIO12;
      *gpio_name = PERIPHS_IO_MUX_MTDI_U;
      return true;
    case 13:
      *gpio_func = FUNC_GPIO13;
      *gpio_name = PERIPHS_IO_MUX_MTCK_U;
      return true;
    case 14:
      *gpio_func = FUNC_GPIO14;
      *gpio_name = PERIPHS_IO_MUX_MTMS_U;
      return true;
    case 15:
      *gpio_func = FUNC_GPIO15;
      *gpio_name = PERIPHS_IO_MUX_MTDO_U;
      return true;
    default:
      return false;
  }
  return true;
}

/**
 * Sets the pull up and pull down registers for a pin.
 * 'pullUp' takes precedence over pullDown
 */
static void ICACHE_FLASH_ATTR
easygpio_setupPullsByName(uint32_t gpio_name, EasyGPIO_PullStatus pullStatus) {

  if (EASYGPIO_PULLUP == pullStatus){
    //PIN_PULLDWN_DIS(gpio_name);
    PIN_PULLUP_EN(gpio_name);
  } else if (EASYGPIO_PULLDOWN == pullStatus){
    PIN_PULLUP_DIS(gpio_name);
    //PIN_PULLDWN_EN(gpio_name);
  } else {
    //PIN_PULLDWN_DIS(gpio_name);
    PIN_PULLUP_DIS(gpio_name);
  }
}

/**
 * Sets the pull up and pull down registers for a pin.
 * 'pullUp' takes precedence over pullDown
 */
bool ICACHE_FLASH_ATTR
easygpio_pullMode(uint8_t gpio_pin, EasyGPIO_PullStatus pullStatus) {
  uint32_t gpio_name;
  uint8_t gpio_func;

  if (!easygpio_getGPIONameFunc(gpio_pin, &gpio_name, &gpio_func) ) {
    return false;
  }

  easygpio_setupPullsByName(gpio_name, pullStatus);
  return true;
}

/**
 * Sets the 'gpio_pin' pin as an input GPIO and sets the pull up and
 * pull down registers for that pin.
 */
bool ICACHE_FLASH_ATTR
easygpio_pinMode(uint8_t gpio_pin, EasyGPIO_PullStatus pullStatus, EasyGPIO_PinMode pinMode) {
  uint32_t gpio_name;
  uint8_t gpio_func;

  if (!easygpio_getGPIONameFunc(gpio_pin, &gpio_name, &gpio_func) ) {
    return false;
  }

  PIN_FUNC_SELECT(gpio_name, gpio_func);
  easygpio_setupPullsByName(gpio_name, pullStatus);

  if (EASYGPIO_OUTPUT != pinMode) {
    GPIO_DIS_OUTPUT(gpio_pin);
  }
  return true;
}

/**
 * Sets the 'gpio_pin' pin as a GPIO and sets the interrupt to trigger on that pin
 */
bool ICACHE_FLASH_ATTR
easygpio_attachInterrupt(uint8_t gpio_pin, EasyGPIO_PullStatus pullStatus, void (*interruptHandler)(int8_t key)) {
  uint32_t gpio_name;
  uint8_t gpio_func;

  if (gpio_pin == 16) {
    os_printf("easygpio_setupInterrupt Error: GPIO16 does not have interrupts\n");
    return false;
  }
  if (!easygpio_getGPIONameFunc(gpio_pin, &gpio_name, &gpio_func) ) {
    return false;
  }

  ETS_GPIO_INTR_ATTACH(interruptHandler, NULL);
  ETS_GPIO_INTR_DISABLE();

  PIN_FUNC_SELECT(gpio_name, gpio_func);

  easygpio_setupPullsByName(gpio_name, pullStatus);

  // disable output
  GPIO_DIS_OUTPUT(gpio_pin);

  gpio_register_set(GPIO_PIN_ADDR(gpio_pin), GPIO_PIN_INT_TYPE_SET(GPIO_PIN_INTR_DISABLE)
                    | GPIO_PIN_PAD_DRIVER_SET(GPIO_PAD_DRIVER_DISABLE)
                    | GPIO_PIN_SOURCE_SET(GPIO_AS_PIN_SOURCE));

  //clear gpio14 status
  GPIO_REG_WRITE(GPIO_STATUS_W1TC_ADDRESS, BIT(gpio_pin));
  ETS_GPIO_INTR_ENABLE();

  return true;
}

/**
 * Detach the interrupt handler from the 'gpio_pin' pin.
 */
bool ICACHE_FLASH_ATTR
easygpio_detachInterrupt(uint8_t gpio_pin) {

  if (gpio_pin == 16) {
    os_printf("easygpio_setupInterrupt Error: GPIO16 does not have interrupts\n");
    return false;
  }

  // Don't know how to detach interrupt, yet.
  // Quick and dirty fix - just disable the interrupt
  gpio_pin_intr_state_set(GPIO_ID_PIN(gpio_pin), GPIO_PIN_INTR_DISABLE);
  return true;
}

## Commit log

2016-03-13 for ys
    [badge.brd, badge.sch]
2016-03-18 switching over to ESP-12e/f
    [badge.brd, badge.sch]
2016-03-21 before the big change
    [badge.brd, badge.sch]
2016-03-22 the change cometh
    [badge.brd, badge.sch]
2016-03-23 before addition of autoreset
    [badge.brd, badge.sch]
2016-03-24 Preliminary Neander v0.0
    [badge.brd, badge.sch, badge_0.0.brd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]
2016-03-24 Schematic: LDO !shdn is to be high, not low
    [badge_0.0.brd, badge_0.0.sch]
2016-03-25 Redid a lot of stuff, added silks.
    [badge_0.0.brd, badge_0.0.sch]
2016-03-25 Fixed the files places
    [badge_0.0.brd, badge_0.0.sch]
2016-03-25 Moved power LED, sharing the r-net for the backlight
    [badge_0.0.brd, badge_0.0.sch]
2016-03-25 DTR and RTS silks on jumper header were swapped
    [badge_0.0.brd]
2016-03-25 Swapped a silks, added more silks, bit of routing changes
    [badge_0.0.brd, badge_0.0.sch]
2016-03-25 Moved a bit of stuff to prevent stop-mask errors, and one dimension error
    [badge_0.0.brd]
2016-03-25 added some changes from YS
    [badge_0.0.brd, badge_0.0.sch]
2016-03-25 Paralleled GND trace, rerouted reset trace for wider separation
    [badge_0.0.brd]
2016-03-25 deleted lone component
    [badge_0.0.brd, badge_0.0.sch]
2016-03-25 Fixed odd shaped reset trace at reset button
    [badge_0.0.brd]
2016-03-25 Minimal nonessential changes
    [badge_0.0.brd, badge_0.0.sch]
2016-03-26 moved res array U to away from RESET button
    [badge_0.0.brd]
2016-03-26 rectified errors in ERC, DRC
    [badge_0.0.brd, badge_0.0.sch]
2016-03-26 routed LED traces away from LCD mounting holes, prevent short between USB case and VBUS
    [badge_0.0.brd]
2016-03-26 Added snapoffable USB-serial
    [badge_0.0.brd, badge_0.0.sch]
2016-03-26 One cap's silk got mangled in the cut path
    [badge_0.0.brd]
2016-03-26 Bit more heatsinking for the battery charger
    [badge_0.0.brd]
2016-03-26 Fixed some silk and mask errors
    [badge_0.0.brd]
2016-03-26 Minor changes
    [badge_0.0.brd]
2016-03-26 Added SJ2 for power LED for reducing power usage
    [badge_0.0.brd, badge_0.0.sch]
2016-03-26 Rerouted and labeled some nets
    [badge_0.0.brd, badge_0.0.sch]
2016-03-27 Replaced 2 resistors with 1 r-net.
    [badge_0.0.brd, badge_0.0.sch]
2016-03-27 Added IO16 <-> Reset; Added mounting holes for LCD; Removed notice for Cutout
    [badge_0.0.brd, badge_0.0.sch]
2016-03-27 added logo, names
    [badge_0.0.brd]
2016-03-27 made logo shiny
    [badge_0.0.brd]
2016-03-27 Repositioned vias, added stop mask for LCD mounts
    [badge_0.0.brd]
2016-03-27 Moved text to bplace
    [badge_0.0.brd]
2016-03-28 before teardown
    [badge_0.0.brd, badge_0.0.sch]
2016-03-28 moved ESP to the opposite end w.r.t. LCD
    [badge_0.0.brd, badge_0.0.sch]
2016-03-28 Added !susp to serial headers. Rerouted many traces
    [badge_0.0.brd, badge_0.0.sch]
2016-03-28 Rerouted stuff. Added new power supply headers near LCD
    [badge_0.0.brd, badge_0.0.sch]
2016-03-28 May not have saved for last commit
    [badge_0.0.brd, badge_0.0.sch]
2016-03-28 fixed XCTF solder mask
    [badge_0.0.brd]
2016-03-28 Fixed most of the errors, optimized some traces
    [badge_0.0.brd]
2016-03-28 added decoup cap; antenna gnd plane; minor edits;
    [badge_0.0.brd, badge_0.0.sch]
2016-03-28 added text to bottom layer; mitred edges;
    [badge_0.0.brd]
2016-03-28 inverted text right way round
    [badge_0.0.brd]
2016-03-29 Edited silkscreen alignments and remove redundant silkscreen markings
    [badge_0.0.brd, badge_0.0.sch]
2016-03-29 changed morse text
    [badge_0.0.brd]
2016-03-29 migrated all caps to 0805
    [badge_0.0.brd, badge_0.0.sch]
2016-05-08 updated board schematics and placement
    [badge_0.1.brd, badge_0.1.sch]
2016-05-09 added testpoints; converted name into pads
    [badge_0.1.brd, badge_0.1.sch]
2016-05-09 Replaced LCD footprint and adjusted nearby traces. New footprint has wider mounting holes and slightly thinner mating connector traces. Also removed a stop mask placed over the connector.
    [badge_0.1.brd, badge_0.1.sch]
2016-05-09 Connect GPIO16 to RESET via diode to enable deep sleep.
    [badge_0.1.brd, badge_0.1.sch]
2016-05-09 Added auto-switch between battery & USB power, just like Huzzah. Removed the need for switch SW1. Since lipo charger output is now the same as regulator input, and C2 & C4 were next to each other, C2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
    [badge_0.1.brd, badge_0.1.sch]
2016-05-09 Moved UP button away from LiPo connector; too close
    [badge_0.1.brd]
2016-05-09 added top mask for LCD pads
    [badge_0.1.brd]
2016-05-10 increased separation between buttons and battery connector; made morse code into pads; edited text descriptions
    [badge_0.1.brd, badge_0.1.sch]
2016-05-10 Added cathode markings for D1 & D2.
    [badge_0.1.brd]
2016-05-19 Fixed transistor layout; Repositioned LCD caps; added 10uF cap to LCD for Brownouts; Increased width of custom layouts; Unbridged 5v; Changed name to FeTChX; ref C; Encoded names; Changed XCTF logo w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
    [badge_0.1.brd, badge_0.1.sch]
2016-05-19 named changed back to neander
    [badge_0.1.brd]
2016-05-19 edits as suggested by YS
    [badge_0.1.brd]
2016-05-19 fixed a small via
    [badge_0.1.brd]
2016-05-19 Added optional connections to the anchors for the battery connector and slide switch To place on schematic, use the invoke tool
    [badge_0.1.brd, badge_0.1.sch]
2016-05-19 removed slant from lcd reset trace upon Yu Siang's rec
    [badge_0.1.brd]
2016-05-19 increased power trace width
    [badge_0.1.brd]
2016-05-20 Added test points for USB data lines.
    [badge_0.1.brd]
2016-05-20 Adjusted LCD mounting holes further apart for snug fit.
    [badge_0.1.brd, badge_0.1.sch]
2016-05-20 Shortened the exposed SMD pads for ESP12-E. They are wayyy too long, just like the tact switches used to be.
    [badge_0.1.brd, badge_0.1.sch]
2016-05-20 Moved buttons and ESP12E to the right, spaced out.
    [badge_0.1.brd]
2016-05-20 Increased ground fills isolation to avoid manufacturing problems.
    [badge_0.1.brd]
2016-05-20 Replaced serial jumpers with a header. Thus removing the need to populate the jumpers during board assembly.
    [badge_0.1.brd, badge_0.1.sch]
2016-05-21 Removed 12K resistor after connecting LCD & ESP resets.
    [badge_0.1.brd, badge_0.1.sch]
2016-05-21 electrons fell out
    [badge_0.1.brd, badge_0.1.sch]
2016-05-21 moved pads and vias out of the way
    [badge_0.1.brd, badge_0.1.sch]
2016-05-21 dunno what I did
    [badge_0.1.brd]
2016-05-21 okey dokey
    [badge_0.1.brd, badge_0.1.sch]
2016-05-21 Fixed VBUS short-circuit overlap on CP2102 breakout
    [badge_0.0.sch, badge_0.1.brd]
2016-05-21 All text back to vector for CAM, minor edits to some routing
    [badge_0.1.brd]
2016-05-21 Routing optimizations Less contorted traces Making use of unused space for routing
    [badge_0.1.brd]
2016-05-21 Added deep-sleep jumper point (closed by default); More routing optimizations
    [badge_0.1.brd, badge_0.1.sch]
2016-05-21 Expanded the power supply area upwards, made all caps same dir
    [badge_0.1.brd]
2016-05-21 Missing sch file from last commit!
    [badge_0.1.sch]
2016-05-21 electrons still dropped out for some strange reason
    [badge_0.1.brd]
2016-05-23 made slot wider for lanyard
    [badge_0.1.brd]
2016-05-23 removed paste from test pads (USB D-/+)
    [badge_ver_C.brd, badge_ver_C.sch]
2016-05-23 updated placements of text, job file
    [badge_ver_C.brd]
2016-05-24 Rename GreyHat's to Greyhats' and added double space to insert line-breaks in credits
2016-06-03 add printout script
2016-07-28 Updated BOM

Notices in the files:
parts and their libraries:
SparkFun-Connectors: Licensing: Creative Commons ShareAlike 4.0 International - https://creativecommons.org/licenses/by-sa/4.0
